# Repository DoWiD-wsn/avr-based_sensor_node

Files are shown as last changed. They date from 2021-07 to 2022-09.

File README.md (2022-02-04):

# AVR-based Sensor Node with Xbee (ASN(x))

The **A**VR-based **S**ensor **N**ode with **X**bee, short **ASN(x)**, is a low-cost platform for low-power sensor nodes specifically for (environmental) monitoring applications, both indoor and outdoor.
It was designed with a focus on energy efficiency and robustness.

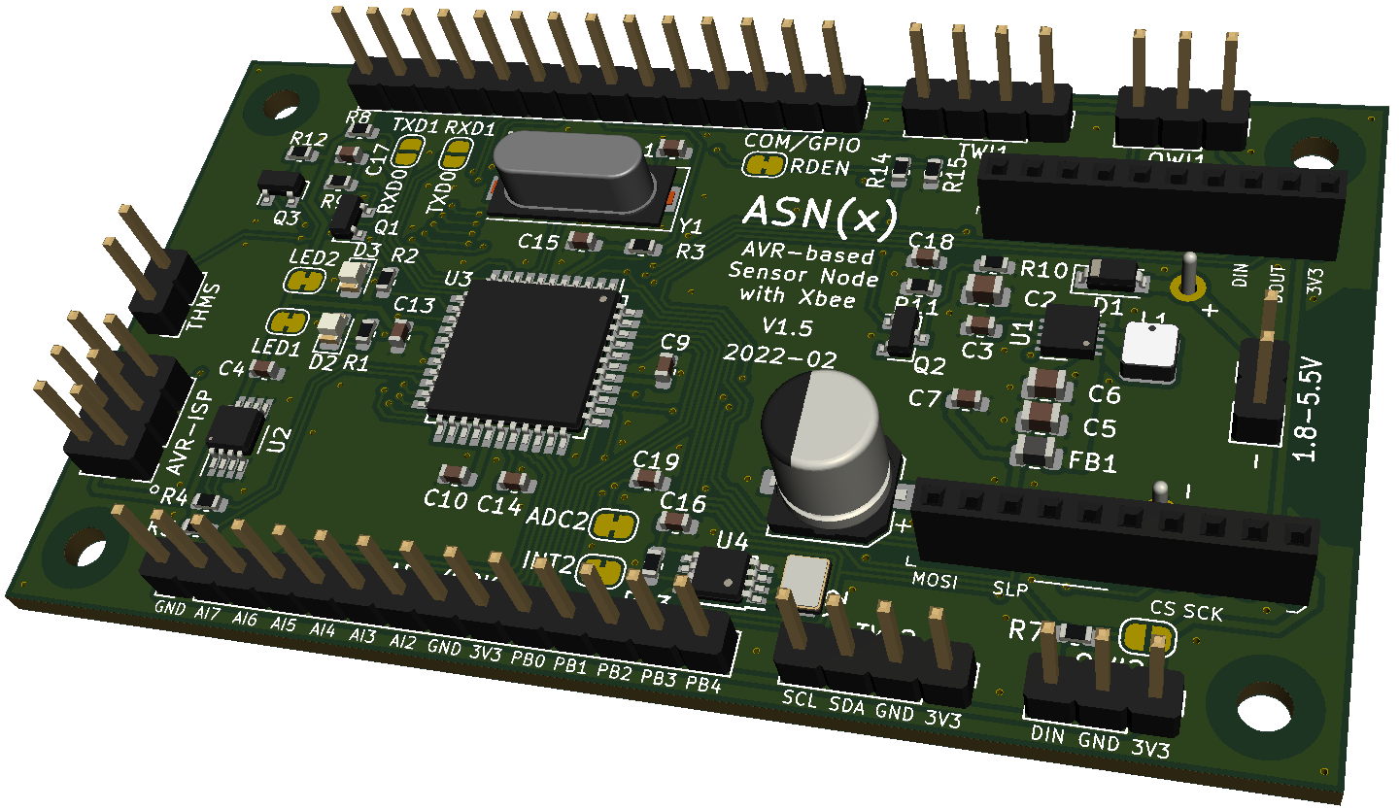
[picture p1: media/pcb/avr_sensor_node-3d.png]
PCB 3D (/media/pcb/avr_sensor_node-3d.png)


## Key Facts

* Compact size of 77 x 43.5 mm
* Powered by two AA batteries (but not limited to; see below)
* [ATmega1284P](docs/datasheets/ATmega1284P.pdf) low-power 8-bit MCU (running at 4MHz)
    * 128kB flash memory
    * 16kB SRAM
    * 4kB EEPROM
* Two UART interfaces
    * one for the radio transceiver
    * one for debug purposes or loopback self-tests
* Programmable via [6-pin AVR-ISP](https://www.mikrocontroller.net/wikifiles/9/97/Avr-isp-pinout.png) connector
* On-board [TMP275](docs/datasheets/TMP275.pdf) temperature sensor (I²C)
* On-board [PCF85263ATT](docs/datasheets/PCF85263A.pdf) RTC as MCU wake-up source (I²C; INT2)
* Fixed 3.3V DC/DC converter [TPS63031DSKR](docs/datasheets/TPS63031DSKR.pdf)
    * Input voltage range: 1.8V to 5.5V
    * Energy efficiency (node power-down): >= 65%
    * Energy efficiency (node active): >= 80%
    * Optimized for low-power mode (<100mA)
* Xbee radio socket
    * UART and SPI connected
    * sleep-request and sleep-indicator pins connected
* Two low-current user LEDs (can be disconnected via cut-through solder jumpers)
* Two solder jumpers to enable bridging of UART0 and UART1 (for loopback self-tests)
* Onboard resistor divider for ADC self-test 
* Onboard resistor divider for battery voltage measurement
* Onboard connector for thermistor temperature measurements
* Two one-wire interface (OWI) connectors (incl. pull-up resistors; separate data pins)
* Two two-wire interface (TWI/I²C) connectors (incl. pull-up resistors)
* 2x14-pin expansion headers

## Contents

```
.
├── docs                : documents & project documentation
│   └── datasheets      : datasheets of components used
├── kicad               : KiCad files
├── media               : Miscellaneous media (images, etc.)
│   ├── pcb             : Photos and rendered images of the PCB
│   └── schematic       : SVG images of the schematics
└── source              : C code library and example programs
```

For more information on the PCB (and its design) refer to [docs/pcb_design.md](docs/pcb_design.md).
The C code library, its functionality, and usage as well as example scripts are presented in [docs/code_library.md](docs/code_library.md).

## Built with

* [KiCad EAD 5.1.9](https://kicad.org/) - PCB design
* [avr-gcc 5.4.0](https://gcc.gnu.org/wiki/avr-gcc) - C code library
* [avr-libc 2.0.0](https://www.nongnu.org/avr-libc/) - C code library

## Contributors

* **Dominik Widhalm** - [***DC-RES***](https://informatics.tuwien.ac.at/doctoral/resilient-embedded-systems/) - [*UAS Technikum Wien*](https://embsys.technikum-wien.at/staff/widhalm/)

Contributions of any kind to improve the project are highly welcome.
For coding bugs or minor improvements simply use pull requests.
However, for major changes or general discussions please contact [Dominik Widhalm](mailto:widhalm@technikum-wien.at?subject=ASN(x)%20on%20GitHub).

## Publications

- Dominik Widhalm, Karl M. Goeschka, and Wolfgang Kastner, "*An open-source wireless sensor node platform with active node-level reliability for monitoring applications*", Sensors 21, no. 22: 7613, 2021, DOI: [10.3390/s21227613](https://doi.org/10.3390/s21227613)

## Changelog

A list of prior versions and changes between the updates can be found in the [CHANGELOG.md](CHANGELOG.md) file.
Note that the major and minor number refer to the hardware version of the ASN(x) board while the patch version is used to denote subsequent software versions.

## Known Issues

A list of known issues with the ASN(x) is available in the [ISSUES.md](ISSUES.md) file.
In this file, we keep track of all kinds of problems/bug and possible fixes for them.

## License

This project is licensed under the MIT License - see the [LICENSE.md](LICENSE.md) file for details.

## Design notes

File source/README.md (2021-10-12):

# ASN(x) C Code Library #

The *ASN(x) C Code Library* is a collection of (mainly) self-written ANSI-C libraries and test applications for the *ASN(x)* sensor node.
It offers basic functionality and helper functions for a range of tasks needed to develop a wireless sensor node based on the *ASN(x)*.
The build system is makefile-based and requires only a minimum number of other libraries and tools.

## Prerequisites ##

In the following, the software requirements for Debian/Ubuntu and Windows machines are listed.

### Debian/Ubuntu ###

To use the *ASN(x) C Code Library*, you need to have `avr-gcc`, `AVR Libc`, and `AVRDUDE` installed:  
  `sudo apt install gcc-avr avr-libc avrdude`  
That's basically it :)

Additionally, to generate the doxygen-based documentation, `doxygen` and `graphviz` are required where the latter one is needed to generate the call-graphs:  
  `sudo apt install doxygen graphviz`

### Windows ###

For Windows-based machines, the `WinAVR` tool can be used. Just download it from [Sourceforge](https://sourceforge.net/projects/winavr/) and install it; it includes `gcc-avr`, `avr-libc`, and `avrdude`. After installing it, you can use the tools from the [windows command prompt](https://www.makeuseof.com/tag/a-beginners-guide-to-the-windows-command-line/).

`Doxygen` can be acquired from [here](https://www.doxygen.nl/download.html) and `Graphviz` can be downloaded from [here](https://graphviz.org/download/).

## Directory Structure ##

```
.
├── _asnx_lib_                         : ASN(x) library files
├── makefile.in                        : Superior makefile to be included
├── 000-blinky_demo                    : Blinky demo to check the toolchain
├── 001-adc_uart_demo                  : ADC to UART output demo
├── 002-sensor_demo                    : Sensor reading demo
├── 003-xbee_demo                      : XBee basic communication demo
├── 004-sensor_node_demo               : Full sensor node demo
├── xyz                                : Further applications
└── ...
```

## AVRDUDE Basic Usage ##

Flashing the MCU and setting its fuses is done with [AVRDUDE](https://www.nongnu.org/avrdude/).
The basic commands are:
* **Flashing**:  
  `avrdude -p atmega1284p -c avrispv2 -P /dev/ttyACM0 -v -U flash:w:BINARY.hex`  
  The same can be achieved via the makefile by executing:  
  `make flash`
* **Erasing**:  
  `avrdude -p atmega1284p -c avrispv2 -P /dev/ttyACM0 -v -e`  
  The same can be achieved via the makefile by executing:  
  `make erase`
* **Write fuses**:
    * *Low fuses*:  
      `avrdude -p atmega1284p -c avrispv2 -P /dev/ttyACM0 -v -U lfuse:w:0xXX:m`
    * *High fuses*:  
      `avrdude -p atmega1284p -c avrispv2 -P /dev/ttyACM0 -v -U hfuse:w:0xXX:m`
    * *Extended fuses*:  
      `avrdude -p atmega1284p -c avrispv2 -P /dev/ttyACM0 -v -U efuse:w:0xXX:m`
    * The default fuse setings for the ASN(x) are:  
      `avrdude -p atmega1284p -c avrispv2 -P /dev/ttyACM0 -v -U lfuse:w:0xED:m -U hfuse:w:0xD9:m -U efuse:w:0xFF:m`  
      The same can be achieved via the makefile by executing:  
      `make defaultfuses`

## XBee 3 Zigbee ##

The XBee 3 is a powerful radio offering a wide range of functions.
In addition to Zigbee, 802.15.4 and Digimesh support (selectable by writing the appropriate firmware), it also has a BLE interface (disabled by default).
Using the BLE interface, you can configure the module using a smartphone in combination with the _Digi XBee Mobile_ app.
However, if you use the XBee for the first time and/or want to configure fresh modules, it is advisable to use Digi's [XCTU](https://www.digi.com/products/embedded-systems/digi-xbee/digi-xbee-tools/xctu) tool on a PC (Windows, Linux, Mac).
For that purpose, you will need to use a XBee to serial adapter such as the [Wavexhare XBee USB Adapter](https://www.waveshare.com/wiki/XBee_USB_Adapter).
Alternatively, the configuration can also be done via the UART interface and AT commands.

There is a [list of libraries](https://www.digi.com/resources/documentation/Digidocs/90001456-13/concepts/c_xbee_libraries_api_mode.htm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) available to interface with the XBee modules.
In addition, you can simply use the module in transparent mode (tunnel UART) or program your own API function (e.g., as shown for [ATmega32](https://www.electronicwings.com/avr-atmega/xbee-interfacing-with-atmega32)).

### Configuration for ASN(x) ###

In the following, the basic configuration of the XBee 3 modules for the use with our ASN(x) sensor nodes is described.
Depending on your application, requirements, etc. you may need to adapt certain parameters.
The explanation of the particular parameters and example configurations can be found in the [XBee 3 User Manual](https://www.digi.com/resources/documentation/digidocs/pdfs/90001539.pdf).
If you use the [XCTU](https://www.digi.com/products/embedded-systems/digi-xbee/digi-xbee-tools/xctu) tool for the configuration, the parameters are grouped to categories; the same as we use below.
Parameters not mentioned in the list below are left at their initial/default value.

* **Networking**
    * `CE` (_device role_)  
        set to `0` (join network).
    * `ID` (_extended PAN ID_)  
        set to a defined address, e.g., `FEDCBA9876543210`.

* **Discovery Options**
    * `NI` (_node identifier_)  
        you can set a user-defined name; we use `SNx` for our devices where `x` is a consecutive number.

* **RF Interfacing**
    * `PL` (_TX power level_)  
        to save energy, we use the lowest value `0` (-5 dBm).

* **Sleep Settings**
    * `SM` (_sleep mode_)  
        to enable the sleep mode, set this value to `1` (pin hibernate).  
        Be careful to have the sleep-request pin at the right logic level; otherwise the XBee goes to sleep and will not be accessible anymore!

* **Bluetooth Options**
    * We use the BLE interface during development to have an easy access to the XBee's setting via the [Digi XBee mobile app](https://www.digi.com/products/embedded-systems/digi-xbee/digi-xbee-tools/digi-xbee-mobile-app).  
        However, in the actual deployment, the BLE interface is deactivated to save energy and for security reasons.
    * `BT` (_Bluetooth enable_)  
        activate the BLE interface by setting this parameter to `1` (you will be asked to set a BLE password).
    * `BI` (_Bluetooth identifier_)  
        optionally, a user-defined BLE identifier can be set to easily identify the single XBees in the mobile app.  
        We use `XBee SNx` where the `SNx` part matches the _NI_ described above.  
        The prefix `XBee` is used to filter the available Bluetooth devices in the mobile app (i.e., only show Bluetooth devices whose identifier starts with `XBee`).
    * `BP` (_Bluetooth power_)  
        to save energy, we use the lowest value `0` (-20 dBm).

* **API Configuration**
    * `AP` (_API enable_)  
        we use the XBee in API mode, therefore, set this parameter to `1` (API mode without escapes).

* **UART Interface**
    * We use the default setting of the UART interface (i.e., 9600 8N1).
    * `BD` (_UART baud rate_)  
        set to `3` (9600 b/s)
    * `NB` (_UART parity_)  
        set to `0` (no parity)
    * `SB` (_UART stop bits_)  
        set to `0` (one stop bit)

* **I/O Settings**
    * To save energy, we deactivate the GPIOs usually used for status information.  
        However, be careful to leave the sleep request and asleep indicator assigned, especially when using pin hibernation!
    * `D5` (_DIO5/Associate Configuration_)  
        set to `0` (disabled)
    * `D8` (_DIO8/Sleep_Rq_)  
        set to `1` (DTR/Sleep_Rq)
    * `D9` (_DIO9/Sleep Indicator_)  
        set to `1` (Awake/Asleep indicator)
    * `P0` (_DIO10/RSSI Configuration_)  
        set to `0` (disabled)

### Resources ###

If you face troubles with the XBee module, have a look at the [common XBee mistakes](https://www.faludi.com/projects/common-xbee-mistakes/) summary.

#### XBee firmwares ####

* [Zigbee](https://www.digi.com/products/embedded-systems/digi-xbee/rf-modules/2-4-ghz-rf-modules/xbee3-zigbee-3)
* [802.15.4](https://www.digi.com/products/embedded-systems/digi-xbee/rf-modules/2-4-ghz-rf-modules/xbee3-802-15-4)
* [Digimesh](https://www.digi.com/products/embedded-systems/digi-xbee/rf-modules/2-4-ghz-rf-modules/xbee3-digimesh-2-4)

#### XBee libraries ####

* [XBee mbed Library](https://os.mbed.com/teams/Digi-International-Inc/code/XBeeLib/)
* [Digi XBee Ansi C Library](https://github.com/digidotcom/xbee_ansic_library/)
* [XBee-arduino](https://github.com/andrewrapp/xbee-arduino)

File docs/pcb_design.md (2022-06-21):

# ASN(x) - PCB Design

The board was designed with KiCad `version 5.1.9` and mainly uses schematic symbols and PCB footprints available in the [KiCad libraries](https://kicad.org/libraries/download/).
Parts not included in these libraries are available as project-specific libraries (see below).
The design requires only a two-layer PCB with all components placed on the top side.
Also, it has enough ground zone area to avoid heating or EMI issues.

## Contents

```
kicad/
├── 3dshapes                        : 3D models of PCB parts
├── myfootprint.pretty              : custom PCB footprints
├── bom                             : interactive HTML BOM
├── avr_sensor_node.kicad_pcb       : PCB layout file
├── avr_sensor_node.pro             : KiCad project file
├── avr_sensor_node.sch             : schematic layout file
├── fp-lib-table                    : project-specific footprint library list
├── mycomponents.dcm                : custom schematic library (descriptions, aliases and keywords)
├── mycomponents.lib                : custom schematic library
└── sym-lib-table                   : project-specific symbol library list
```

## Costs

The cost of one *ASN(x)* is around 20€ for the components (2021-05; [Farnell](https://www.farnell.com/)), around 10€ for the PCB ([PCB Pool / Beta Layout](https://eu.beta-layout.com/pcb/)), and around 20€ for the Xbee 3 radio (normal version, not pro).
Thus, the total costs of one *ASN(x)* are around **50€**.
Depending on the supplier and quantities ordered, the costs may vary.

## Schematic

**Main schematic**:  
Main Schematic (/media/schematic/avr_sensor_node.svg)

## Header Pinout
 
PCB header pinout (/media/pcb/avr_sensor_node-pinout.svg)

## PCB Design

Front:  
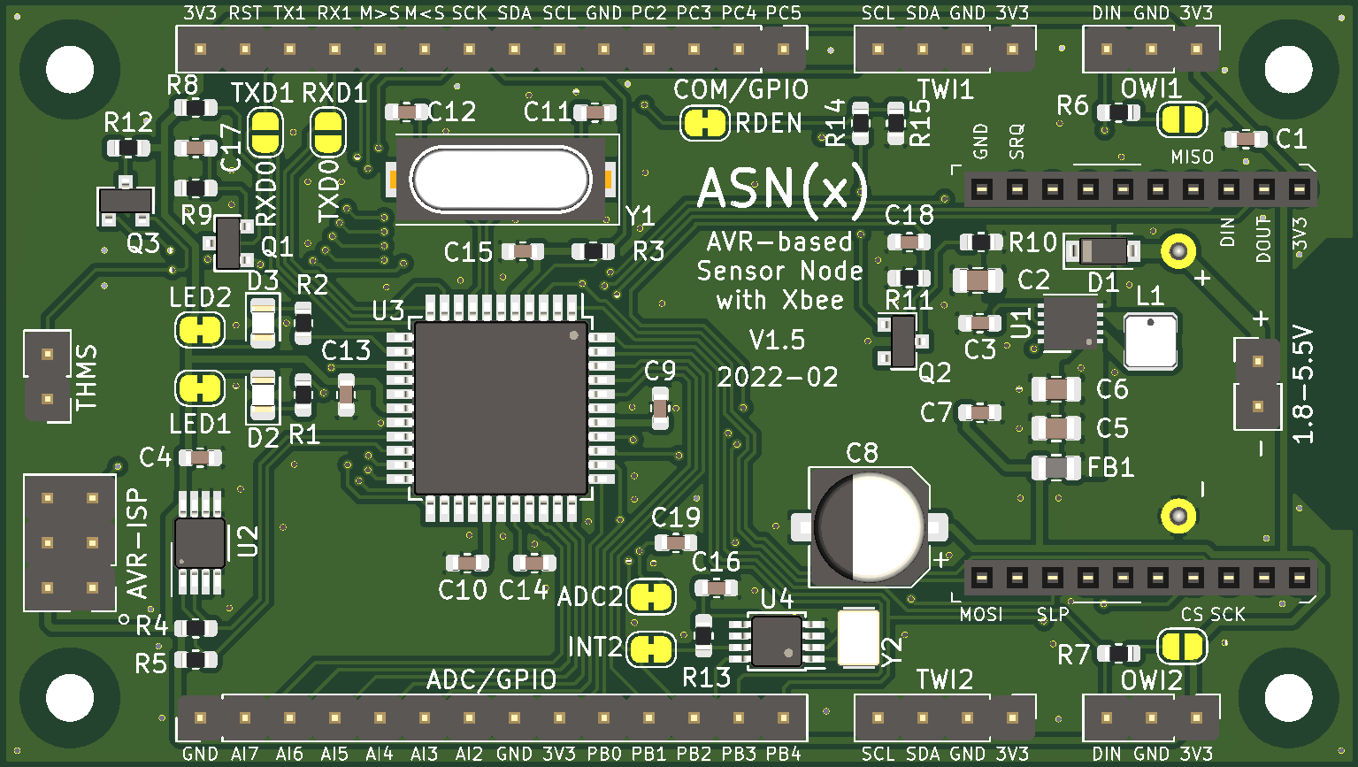
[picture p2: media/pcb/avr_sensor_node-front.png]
PCB front (/media/pcb/avr_sensor_node-front.png)


Back:  
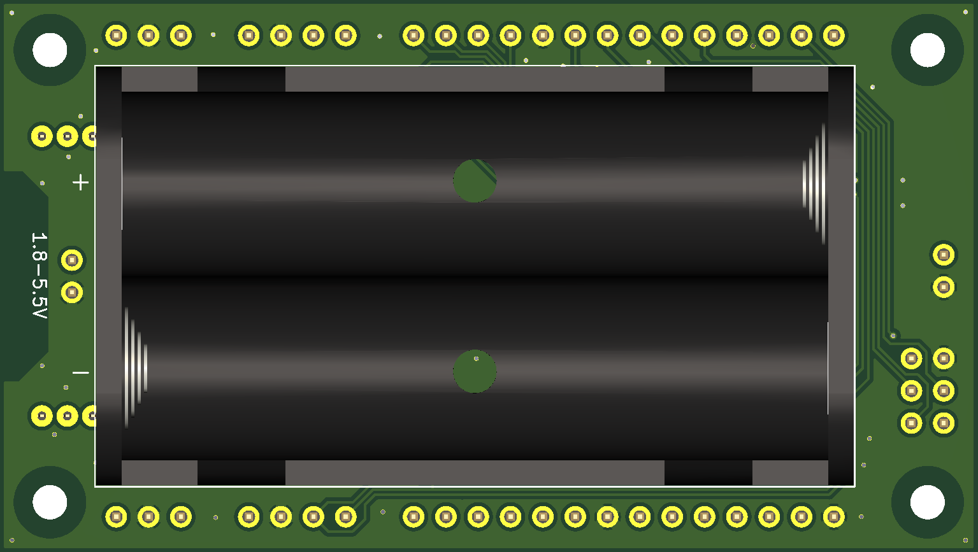
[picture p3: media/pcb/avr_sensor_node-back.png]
PCB back (/media/pcb/avr_sensor_node-back.png)


For the PCB design the following rules were used:
* Design rules:
    * Minimum track width: `0.15 mm`
    * Minimum via diameter: `0.6 mm`
    * Minimum via drill: `0.3 mm`
    * Minimum hole to hole: `0.25 mm`
    * `Prohibit overlapping courtyards`
* Tracks:
    * `0.2 mm`
    * `0.25 mm`
    * `0.4 mm`
    * `0.8 mm`
* Vias:
    * Size: `0.6 mm`
    * Drill: `0.3 mm`
* Zones:
    * Clearance: `0.3 mm`
    * Minimum width: `0.18 mm`
    * Pad connections: `Thermal reliefs`
    * Thermal clearance: `0.18 mm`
    * Thermal spoke width: `0.8 mm`

## Components and Libraries

An interactive BOM can be found in the `/kicad/bom/` directory (see [here](../kicad/bom/avr_sensor_node.html); created with [InteractiveHtmlBom](https://github.com/openscopeproject/InteractiveHtmlBom)).

| Reference | Value | Symbol Library | Symbol | Footprint Library | Footprint | Dist. |
|---|---|---|---|---|---|---|
| C11-C12 | 18pF  | Device | C | Capacitor_SMD | C_0603_1608Metric | [Farnell](https://at.farnell.com/kemet/c0603c180k5ractu/kondensator-18pf-50v-10-x7r-0603/dp/2821151) |
| C14 | 47nF  | Device | C | Capacitor_SMD | C_0603_1608Metric | [Farnell](https://at.farnell.com/yageo/cc0805krx7r9bb473/kondensator-0-047-f-50v-10-x7r/dp/718683) |
| C1,C3-C4,C7,C8,C10,C13,C15-C19  | 100nF | Device | C | Capacitor_SMD | C_0603_1608Metric | [Farnell](https://at.farnell.com/kemet/c0603c104m5ractu/kondensator-0-1-f-50v-20-x7r-0603/dp/2581046) |
| C2,C5,C6  | 10uF  | Device | C | Capacitor_SMD | C_0805_2012Metric | [Farnell](https://at.farnell.com/murata/grm21br71a106ka73l/kondensator-10-f-10v-10-x7r-0805/dp/2611944) |
| C8 | 100uF | Device | C | Capacitor_SMD | CP_Elec_6.3x7.7 | [Farnell](https://at.farnell.com/kemet/edk107m016a9gaa/kondensator-100-f-16v-radial-smd/dp/2068653) |
| L1 | 1.5uH | Device | L | *myfootprint*`*`  | L_Coilcraft_LPS3015 | [Farnell](https://at.farnell.com/coilcraft/lps3015-152mrb/induktivit-t-1-5uh-20-1-3a-gesch/dp/2408018?st=1.5) |
| FB1 | - | Device | Ferrite_Bead | Inductor_SMD | L_0805_2012Metric | [Farnell](https://at.farnell.com/laird/mi0805k400r-10/ferritperle-2012-100mhz-40r/dp/2292459) |
| R1-R2 | 560ohm | Device | R | Resistor_SMD | R_0603_1608Metric | [Farnell](https://at.farnell.com/yageo/ac0603fr-07560rl/dickschichtwiderstand-560r-1-0/dp/3495281) |
| R3-R15 | 10k | Device | R | Resistor_SMD | R_0603_1608Metric | [Farnell](https://at.farnell.com/yageo/ac0603fr-0710kl/dickschichtwiderstand-10k-1-0/dp/3495224) |
| D2-D3 | green | Device | LED | LED_SMD | LED_0805_2012Metric | [Farnell](https://at.farnell.com/kingbright/kp-2012lsgc/led-gr-n-0-8mcd-568nm-smd/dp/2463991) |
| D1 | schottky | Device  | D_Schottky | Diode_SMD | D_SOD-123 | [Farnell](https://at.farnell.com/stmicroelectronics/stps0520z/schottky-diode-2a-20v-smd/dp/1467545) |
| Q1-Q3 | BSS138 | Transistor_FET | BSS138 | Package_TO_SOT_SMD | SOT-23 | [Farnell](https://at.farnell.com/nexperia/bss138bk-215/mosfet-n-kanal-60v-0-36a-sot23/dp/2053833) |
| U2 | - | *mycomponents*`*` | TMP275 | Package_SO | VSSOP-8_3.0x3.0mm_P0.65mm | [Farnell](https://at.farnell.com/texas-instruments/tmp275aidgkr/temperature-sensor-0-0625deg-c/dp/3009081) |
| U3 | - | *mycomponents*`*` | ATmega1284P | Package_QFP | TQFP-44_10x10mm_P0.8mm | [Farnell](https://at.farnell.com/microchip/atmega1284p-au/mcu-8bit-avr-128k-flash-44tqfp/dp/1715480) |
| U1 | - | *mycomponents*`*` | TPS63031 | Package_SON | VSON-10-1EP_3x3mm_P0.5mm_EP1.2x2mm_ThermalVias | [Farnell](https://at.farnell.com/texas-instruments/tps63031dskr/dc-dc-conv-buck-boost-2-4mhz-vson/dp/3122997) |
| U4 | - | *mycomponents*`*` | PCF85263ATT | Package_SO | TSSOP-8_3x3mm_P0.65mm | [Farnell](https://at.farnell.com/nxp/pcf85263att-aj/echtzeituhr-5-5v-i2c-tssop-8/dp/2775936) |
| Y1 | 4MHz  | Device | Crystal | Crystal | Crystal_SMD_HC49-SD | [Farnell](https://at.farnell.com/txc/9c-4-000maaj-t/xtal-4-000mhz-18pf-smd-hc-49s/dp/1842332) |
| Y2 | 32.768kHz  | Device | Crystal | Crystal | Crystal_SMD_3215-2Pin_3.2x1.5mm | [Farnell](https://at.farnell.com/abracon/abs07-lr-32-768khz-6-1-t/quarz-32-768khz-6pf-3-2mm-x-1/dp/2849465) |
| J6,J9 | - | Connector_Generic | Conn_01x02 | Connector_PinHeader_2.54mm | PinHeader_1x02_P2.54mm_Vertical | [Farnell](https://at.farnell.com/wurth-elektronik/61304011121/stiftleiste-2-54mm-tht-vertikal/dp/2356175) |
| J2-J3 | - | Connector_Generic | Conn_01x03 | Connector_PinHeader_2.54mm | PinHeader_1x03_P2.54mm_Vertical | [Farnell](https://at.farnell.com/wurth-elektronik/61304011121/stiftleiste-2-54mm-tht-vertikal/dp/2356175) |
| J4-J5 | - | Connector_Generic | Conn_01x04 | Connector_PinHeader_2.54mm | PinHeader_1x04_P2.54mm_Vertical | [Farnell](https://at.farnell.com/wurth-elektronik/61304011121/stiftleiste-2-54mm-tht-vertikal/dp/2356175) |
| J7-J8 | - | Connector_Generic | Conn_01x14 | Connector_PinHeader_2.54mm | PinHeader_1x14_P2.54mm_Vertical | [Farnell](https://at.farnell.com/wurth-elektronik/61304011121/stiftleiste-2-54mm-tht-vertikal/dp/2356175) |
| J1 | - | Connector | AVR-ISP-6 | Connector_PinHeader_2.54mm | PinHeader_2x03_P2.54mm_Vertical | [Farnell](https://at.farnell.com/wurth-elektronik/61304021121/stiftleiste-2-54mm-tht-vertikal/dp/2356148) |
| JP1 | Xbee | *mycomponents*`*` | Xbee3 | *myfootprint*`*` | XBEE-20_THT | [Farnell](https://at.farnell.com/te-connectivity/1-2314878-0/buchsenleiste-10pos-1-reihe-2mm/dp/3289695) |
| JP2-JP3,JP6-JP7 | bridged | Jumper | SolderJumper_2_Bridged | Jumper | SolderJumper-2_P1.3mm_Bridged_RoundedPad1.0x1.5mm | - |
| JP4-JP5,JP9-JP10| open | Jumper | SolderJumper_2_Open | Jumper | SolderJumper-2_P1.3mm_Open_RoundedPad1.0x1.5mm | - |
| H1-H4 | - | Mechanical | MountingHole  | MountingHole | MountingHole_2.7mm_M2.5 | - |

If your installation of KiCad is missing (some of) the standard libraries, you can download them from [KiCad libraries](https://kicad.org/libraries/download/).
The custom libraries required (marked with `*`) are all contained in this repository.

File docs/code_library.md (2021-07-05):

# ASN(x) C Code Library #

The ASN(x) comes with a software library written in ANSI-C language, called `ASNX LIB`, to lower the entry barrier and ease the development of the node's software.
It provides a set of modules for the interaction with the AVR MCU's on-chip peripherals (e.g., ADC, UART, timer), several external sensor libraries connected via I²C or a one-wire interface (OWI), a high-level library to communicate with the Xbee 3 radio transceiver, and high level modules to support unit conversions as well as packing sensor values into messages (including a fixed-point number representation).

The libraries where self-written (unless otherwise specified) and have only a small number of dependencies.
That is, they only require `AVR Libc` to be available on the system and a recent version of `avr-gcc` for the compilation.
To flash the application on the MCU, either the tools provided by [Atmel](https://www.microchip.com/en-us/development-tools-tools-and-software) or `AVRDUDE` can be used.
For more information on the installation of those and the basic usage of `AVRDUDE` refer to the source directory's [README](../source/README.md).

To further ease the development of the ASN(x) software part, we provide a superior makefile that offers basic functionality in a convenient way, namely
* `flash` ... the flashing of a binary onto the MCU
* `clean` ... the cleaning of intermediate files
* `erase` ... the erasing of the MCU (clear the flash memory)
* `defaultfuses` ... the programming of the default fuse settings (lb: `0xDD`, hb: `0xD9`, eb: `0xff`)
* `doc` ... the generation of the libraries doxygen documentation
* `distclean` ... the cleaning of everything, that is, intermediate files and documentary

The generation of the documentation requires doxygen and dotviz (to generate the call-graphs), see [README](../source/README.md).

## ASNX LIB dependencies ##

As mentioned above, the ASN(x) software library has only little external dependencies (i.e., `AVR Libc`).
Additionally, the internal structure was kept shallow to minimize the modules' cross-dependencies and keep the software complexity as low as reasonably possible.

## Prepared demo applications ##

In the source directory, you can also find five pre-prepared demo applications.
They show the usage of the `ASNX LIB` and the ASN(x) components in a bottom-up fashion.

### 000-blinky_demo ###

The `blinky demo` is intended to help getting familiar with the toolchain and getting the hardware up and running (i.e., compilation and flashing of the software)
If everything worked, the two user LEDs will blink alternately with a delay of 500ms.
This demo only uses the `LED` module.

### 001-adc_uart_demo ###

The second demo application additionally shows the usage of the `ADC` and the `UART` modules as well as a simple `printf` library.
In the demo, the MCU's supply voltage and the battery voltage are read once per second (via the `ADC`) and the results are printed using the `printf` library on the `UART1` interface.

### 002-sensor_demo ###

The `sensor demo` depicts the usage of the provided external sensor libraries and the timer-based systick timer.
The following sensors are currently supported:
* DS18B20 temperature sensor (OWI)
* AM2302 temperature/humidity sensor (DHT22; OWI)
* BME280 environmental sensor (TWI)
* TMP275 on-board temperature sensor (TWI)
* LM75 temperature sensor (similar to TMP275; TWI)
* STEMMA soil humidity sensor (TWI)

Additionally, the MCU surface temperature measurement via the on-board voltage divider and an external 103JT thermistor (10kOhm @25°C) based on the Steinhart–Hart equation is supported.
All sensor values are read and printed via UART in a definable interval controlled by the systick timer.

### 003-xbee_demo ###

The fourth demo application shows the interaction with the Xbee 3 radio module connected via UART0.
It sends a steadily increasing number via unicast to a specified network participant (specified via its 64-bit MAC address) every 2 seconds and checks the transmission response (acknowledgment).

### 004-sensor_node_demo ###

The last demo, the full `sensor node demo`, shows an example of a full sensor node including Xbee communication, sensor readings, and sleep modes.
In this demo also the on-board RTC is used as a wake-up source for the MCU when it is sleeping.
Basically, the sensor node is woken up every 10 minutes (interval can be configured), reads the current sensor values, sends them to a defined network participant and goes back to sleep (power-down mode).
In addition to the basic sensor readings, also some diagnostic data are sent.

## Development of an own application ##

To create an own application, we suggest the following procedure:
* Create a new directory in the source folder.
* Create a C source file in the newly created directory (e.g., `APPLICATION_NAME.c`)
* Put a makefile into the new directory that contains at least:
  * `TARGET = APPLICATION_NAME`
  * `include ../makefile.in`
  * Additionally, also the port or other specific settings can be configured in the makefile.

That's it.
You are ready to code your own application.

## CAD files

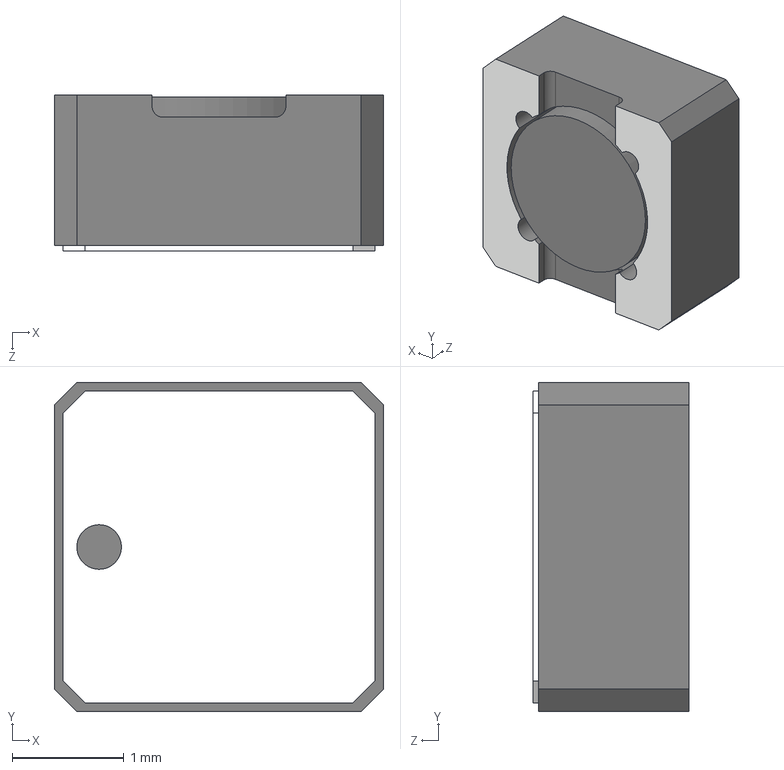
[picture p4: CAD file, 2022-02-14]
kicad/3dshapes/L_Coilcraft_LPS3015.step
2.95 x 2.95 x 1.40 mm

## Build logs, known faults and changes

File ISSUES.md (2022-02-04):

# Known Issues

In the following, known issues with the ASN(x) soft- or hardware are listed and possible fixes are provided.
Currently, the following issues are known:

* [DC/DC Converter Startup](#dcdc-converter-startup)

## DC/DC Converter Startup

The ASN(x) uses a [TPS63031DSKR](docs/datasheets/TPS63031DSKR.pdf) low-power DC/DC converter with a fixed output voltage of 3.3 V.
While providing a stable supply for the sensor node with a comparably high energy efficiency, we found one issue that may be bothersome during sensor node software development.
That is, when a voltage supply is connected to the DC/DC converter's output (e.g., by an AVR ISP programmer with built-in supply) the converter sometimes does not start-up (work) properly, even if the second source is removed.

A solution to this issue is to make sure not to drive the programmers (or whatever is connected) internal supply; most AVR ISP programmer we found allow one to disable the supply voltage.
However, in case you face this issue it normally helps to remove all power sources from the ASN(x) and leave it unpowered for several minutes.
Normally, after that the sensor node can be normally used again.

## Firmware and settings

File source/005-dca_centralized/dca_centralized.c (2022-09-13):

/*!
 * @brief   Implementation of a centralized DCA for fault detection
 *
 * Implementation of the dendritic cell algorithm (DCA) in a centralized
 * manner to detect faults. The DCA itself runs on the sink node, but
 * the detection is augmented by the node-level fault indicators that
 * are reported by every sensor node in the network.
 *
 * The procedure is as follows:
 * 1.)  initialize modules
 * 2.)  connect to the Zigbee network
 * 3.1) reset RTC (stop-watch mode)  <--+
 * 3.2) enable modules/sensors          |
 * 3.3) query sensors                   |
 * 3.4) perform self-diagnostics        |
 * 3.5) send values via Zigbee          |
 * 3.6) disable modules/sensors         |
 * 3.7) put MCU to sleep                |
 *  +-----------------------------------+
 *
 * @file    /005-dca_centralized/dca_centralized.c
 * @author  Dominik Widhalm
 * @version 2.2.0
 * @date    2022/09/13
 */


/*** APP CONFIGURATION ***/
#define ENABLE_DBG                  0               /**< Enable debug output via UART1 (9600 BAUD) */
#define ENABLE_DBG_MSG              0               /**< Enable debug output of message content */
#define ENABLE_DBG_INDICATOR        0               /**< Enable debug output of indicator values */
#define UPDATE_INTERVAL             5               /**< Update interval [min] */
#define ASNX_VERSION_MINOR          5               /**< Minor version number of the used ASN(x) */
/* Zigbee network */
#define ZIGBEE_ENABLE_ACK           0               /**< Enable (1) or disable (0) transmit response */
/* Enable (1) or disable (0) sensor measurements */
#define ENABLE_DS18B20              0               /**< enable DS18B20 sensor */
#define ENABLE_AM2302               0               /**< enable AM2302 sensor */
#define ENABLE_SHTC3                0               /**< enable SHTC3 sensor */
#define ENABLE_SHT30                1               /**< enable SHT30 sensor (addon board) */
/* Check configuration */
#if (ENABLE_AM2302 && ENABLE_SHTC3) || (ENABLE_AM2302 && ENABLE_SHT30) || (ENABLE_SHTC3 && ENABLE_SHT30)
#  error "Use either AM2302, SHTC3 or SHT30 for air measurements, but not several!"
#endif


/***** INCLUDES *******************************************************/
/*** STD ***/
#include <math.h>
/*** AVR ***/
#include <avr/io.h>
#include <avr/interrupt.h>
#include <avr/sleep.h>
#include <avr/wdt.h>
#include <util/delay.h>
/*** ASNX LIB ***/
/* MCU */
#include "adc/adc.h"
#include "hw/led.h"
#include "i2c/i2c.h"
#include "timer/timer.h"
#include "uart/uart.h"
/* Radio */
#include "xbee/xbee.h"
#if ASNX_VERSION_MINOR>0
/* RTC */
#  include "rtc/pcf85263.h"
#else
/* SysTick */
#  include "timer/systick.h"
#endif
/* Sensors */
#include "sensors/tmp275.h"
#if ENABLE_DS18B20
#  include "sensors/ds18x20.h"
#endif
#if ENABLE_AM2302
#  include "sensors/dht.h"
#endif
#if ENABLE_SHTC3
#  include "sensors/shtc3.h"
#endif
#if ENABLE_SHT30
#  include "sensors/sht30.h"
#endif
/* Misc */
#include "util/diagnostics.h"
#include "util/fixed_point.h"
#include "util/sensor_msg.h"
#if ENABLE_DBG
#  include "util/printf.h"
#else
#  define printf(...) do { } while (0)
#endif
/* DCA */
#include "dca/indicators.h"


/***** STRUCTURES *****************************************************/
/*!
 * A structure to store the sensor and indicator values.
 */
typedef struct {
    /* additional data */
    uint16_t time;          /**< timestamp (2 byte) */
    /* use case data */
    uint16_t t_air;         /**< air temperature (fixed point) */
    uint16_t h_air;         /**< air humidity (fixed point) */
    uint16_t t_soil;        /**< soil temperature (fixed point) */
    uint16_t h_soil;        /**< soil humidity (fixed point) */
    /* battery SoC */
    uint8_t soc;            /**< battery state-of-charge (fixed point) */
    /* indicator */
    uint8_t danger;         /**< danger indicator (fixed point) */
    uint8_t safe;           /**< safe indicator (fixed point) */
} MSG_t;


/***** GLOBAL VARIABLES ***********************************************/
#if ASNX_VERSION_MINOR==0
/*! Variable (flag) for barrier synchronization */
volatile uint8_t barrier = 1;
#endif
/*!
 * Put a MCUSR register dump into the .noinit section.
 * @see https://www.nongnu.org/avr-libc/user-manual/group__avr__watchdog.html
 */
uint8_t MCUSR_dump __attribute__ ((section (".noinit"))) \
                   __attribute__ ((used));             // Needed for LTO


/***** LOCAL FUNCTION PROTOTYPES **************************************/
void get_mcusr(void) __attribute__((naked)) \
                     __attribute__((section(".init3"))) \
                     __attribute__((used));            // Needed for LTO
void sleep_until_reset(void);
#if ASNX_VERSION_MINOR==0
void update(void);
#endif
#if ENABLE_DBG_MSG
void dbg_print_msg(MSG_t* msg);
#endif
#if ENABLE_DBG_INDICATOR
void dbg_print_indicator(float danger, float safe, float x_nt, float x_vs, float x_bat, float x_art, float x_rst, float x_ic, float x_adc, float x_usart, float t_air_i, float h_air_i, float t_soil_i, float h_soil_i);
#endif


/***** LOCAL FUNCTIONS ************************************************/
/*!
 * Turn off the WDT as early in the startup process as possible.
 * @see https://www.nongnu.org/avr-libc/user-manual/group__avr__watchdog.html
 */
void get_mcusr(void) {
    /* Make a copy of the MCUSR */
    MCUSR_dump = MCUSR;
    /* Reset the actual MCUSR */
    MCUSR = 0;
    /* Disable the WDT */
    wdt_disable();
}


/*!
 * Activate WDT with given delay, put MCU to sleep and wait for reset.
 */
void sleep_until_reset(void) {
    /* Enable Watchdog with 60ms delay */
    wdt_enable(WDTO_60MS);
    /* Put MCU to sleep */
    sleep_enable();
    sleep_bod_disable();
    sleep_cpu();
}


#if ASNX_VERSION_MINOR==0
/***
 * Callback function to be called by the systick timer.
 ***/
void update(void) {
    static uint8_t cnt = 0;
    /* Check if update time has elapsed */
    if(++cnt >= UPDATE_INTERVAL) {
        /* Reset counter */
        cnt = 0;
        /* Set barrier sync flag */
        barrier = 1;
    }
}
#endif


/*!
 * Debug: print the contents of a given sensor message structure
 */
#if ENABLE_DBG_MSG
void dbg_print_msg(MSG_t* msg) {
    printf("\n===== SENSOR MESSAGE CONTENTS =====\n");
    printf("%d message updates\n",msg->time);
    printf("=== SENSOR VALUES ===\n");
    printf("T_air: %.2f C\n",fp_fixed16_to_float_10to6(msg->t_air));
    printf("H_air: %.2f %%\n",fp_fixed16_to_float_10to6(msg->h_air));
    printf("T_soil: %.2f C\n",fp_fixed16_to_float_10to6(msg->t_soil));
    printf("H_soil: %.2f %%\n",fp_fixed16_to_float_10to6(msg->h_soil));
    printf("=== BATTERY ===\n");
    printf("SoC: %d\n",msg->soc);
    printf("=== SENSOR VALUES ===\n");
    printf("Danger: %.2f\n",fp_fixed8_to_float_2to6(msg->danger));
    printf("Safe: %.2f\n",fp_fixed8_to_float_2to6(msg->safe));
    printf("===================================\n\n");
}
#endif


/*!
 * Debug: print the values of the single indicator shares
 */
#if ENABLE_DBG_INDICATOR
void dbg_print_indicator(float danger, float safe, float x_nt, float x_vs, float x_bat, float x_art, float x_rst, float x_ic, float x_adc, float x_usart, float t_air_i, float h_air_i, float t_soil_i, float h_soil_i) {
    printf("\n===== INDICATOR VALUES =====\n");
    printf("danger: %.2f\n",danger);
    printf("safe: %.2f\n",safe);
    printf("=== DANGER/FAULT INDICATORS ===\n");
    printf("X_NT: %.2f\n",x_nt);
    printf("X_VS: %.2f\n",x_vs);
    printf("X_BAT: %.2f\n",x_bat);
    printf("X_ART: %.2f\n",x_art);
    printf("X_RST: %.2f\n",x_rst);
    printf("X_IC: %.2f\n",x_ic);
    printf("X_ADC: %.2f\n",x_adc);
    printf("X_UART: %.2f\n",x_usart);
    printf("=== SAFE INDICATORS ===\n");
    printf("T_AIR: %.2f\n",t_air_i);
    printf("H_AIR: %.2f\n",h_air_i);
    printf("T_SOIL: %.2f\n",t_soil_i);
    printf("H_SOIL: %.2f\n",h_soil_i);
    printf("===================================\n\n");
}
#endif


/***** MAIN ***********************************************************/
/*!
 * Main function of the application.
 */
int main(void) {
    /*** Local variables ***/
    /* Message data structure */
    MSG_t msg = {0};
#if ASNX_VERSION_MINOR>0
    /* Date/time structure */
    PCF85263_CNTTIME_t time = {0};
#endif
    /* Sensor handles */
    TMP275_t tmp275;                /* TMP275 sensor device structure */
#if ENABLE_DS18B20
    DS18X20_t ds18b20;              /* DS18B20 sensor device structure */
    uint8_t ds18b20_en = 0;         /* Sensor enable flag */
#endif
#if ENABLE_AM2302
    DHT_t am2302;                   /* AM2302 sensor device structure */
    uint8_t am2302_en = 0;          /* Sensor enable flag */
#endif
#if ENABLE_SHTC3
    SHTC3_t shtc3;                  /* SHTC3 sensor device structure */
    uint8_t shtc3_en = 0;           /* Sensor enable flag */
#endif
#if ENABLE_SHT30
    SHT30_t sht30;                  /* SHT30 sensor device structure */
    uint8_t sht30_en = 0;           /* Sensor enable flag */
#endif
    /* Temporary sensor measurement variables */
#if (ENABLE_DS18B20 || ENABLE_AM2302 || ENABLE_SHTC3 || ENABLE_SHT30)
    float measurement = 0.0;
#endif
#if (ENABLE_AM2302 || ENABLE_SHTC3 || ENABLE_SHT30)
    float measurement2 = 0.0;
#endif
    /* Diagnostic values */
    float v_bat=0.0, v_mcu=0.0, v_trx=0.0;
    float t_mcu=0.0, t_trx=0.0, t_brd=0.0;
    /* Sensor values */
    float t_air_t=0.0, h_air_t=0.0, t_soil_t=0.0, h_soil_t=0.0;
    /* Fault indicator */
    float x_nt=0.0, x_vs=0.0, x_bat=0.0, x_art=0.0, x_rst=0.0, x_ic=0.0, x_adc=0.0, x_usart=0.0;
    /* Safe indicator */
    float t_air_i=0.0, h_air_i=0.0, t_soil_i=0.0, h_soil_i=0.0;
    safe_t t_air_s, h_air_s, t_soil_s, h_soil_s;
    /* Aggregated indicator */
    float danger=0.0, safe=0.0;
    /* Runtime measurement */
    uint16_t runtime = 0, runtime_ms = 0;
    /* Function return value */
    int8_t ret = 0;


    /*** 1.) initialize modules ***************************************/
    /* Configure the sleep mode */
    set_sleep_mode(SLEEP_MODE_PWR_DOWN);
    /* Disable unused hardware modules */
#if ASNX_VERSION_MINOR>0
    PRR0 = _BV(PRTIM2) | _BV(PRTIM0) | _BV(PRSPI);
#else
    PRR0 = _BV(PRTIM2) | _BV(PRSPI);
#endif
    
#if ENABLE_DBG
    /* Initialize UART1 for debug purposes (9600 baud) */
    uart1_init(9600UL);
    /* Initialize the printf function to use the uart1_write_char() function for output */
    printf_init(uart1_write_char);
#else
    /* Disable UART1 */
    PRR0 |= _BV(PRUSART1);
#endif
    /* Print welcome message */
    printf("=== STARTING UP ... ===\n");
    
    /* Initialize the user LEDs and disable both by default */
    led_init();
    /* Initialize the ADC */
    adc_init(ADC_ADPS_32,ADC_REFS_VCC);
    adc_disable_din(0x07);
    /* Initialize I2C master interface */
    i2c_init();
    /* Initialize Xbee 3 (uses UART0 @9600 baud; receive via ISR) */
    uart0_init(9600UL);
    uart0_interrupt_enable();
    xbee_init(uart0_write_byte, uart0_pop_byte, uart0_rx_buffer_cnt);
    /* Status message */
    printf("Communication interfaces initialized ...\n");
    
    /* Initialize the diagnostic circuitry */
    diag_init();
    diag_disable();
    /* Initialize the fault indicators */
    indicators_init();
    /* Initialize the safe indicators */
    safe_init(&t_air_s);
    safe_init(&h_air_s);
    safe_init(&t_soil_s);
    safe_init(&h_soil_s);
    /* Status message */
    printf("Indicators initialized ...\n");

#if ASNX_VERSION_MINOR>0
    /* Initialize the RTC */
    time.minutes = UPDATE_INTERVAL;
    ret = pcf85263_init_wakeup_src(&time);
    if(ret != PCF85263_RET_OK) {
        printf("Couldn't initialize RTC (%d) ... aborting!\n",ret);
        sleep_until_reset();
    }
    /* Configure INT2 to fire interrupt when logic level is "low" */
    EICRA = 0x00;
    EIMSK = _BV(INT2);
#else
    /* Initialize the systick timer */
    systick_init();
    /* Set a systick callback function to be called every second */
    systick_set_callback_min(update);
#endif

    /* Enable interrupts globally */
    sei();

    /* Initialize the TMP275 sensor */
    ret = tmp275_init(&tmp275, TMP275_I2C_ADDRESS);
    if(ret != TMP275_RET_OK) {
        printf("Couldn't initialize TMP275 (%d) ... aborting!\n",ret);
        sleep_until_reset();
    }
    /* Configure the TMP275 sensor (SD; 10-bit mode) */
    ret = tmp275_set_config(&tmp275, 0x21);
    if(ret != TMP275_RET_OK) {
        printf("Couldn't configure TMP275 (%d) ... aborting!\n",ret);
        sleep_until_reset();
    }
    /* Status message */
    printf("TMP275 initialized ...\n");

#if ENABLE_DS18B20
    /* Initialize the DS18B20 sensor */
    ret = ds18x20_init(&ds18b20, &DDRD, &PORTD, &PIND, PD6);
    if(ret != DS18X20_RET_OK) {
        printf("Couldn't initialize DS18B20 (%d)!\n",ret);
        ds18b20_en = 0;
    } else {
        printf("DS18B20 initialized ...\n");
        ds18b20_en = 1;
    }
#endif

#if ENABLE_AM2302
    /* Initialize the AMS2302 sensor */
    ret = dht_init(&am2302, &DDRD, &PORTD, &PIND, PD7, DHT_DEV_AM2302);
    if(ret != DHT_RET_OK) {
        printf("Couldn't initialize AMS2302 (%d)!\n",ret);
        am2302_en = 0;
    } else {
        printf("AMS2302 initialized ...\n");
        am2302_en = 1;
    }
#endif

#if ENABLE_SHTC3
    /* Initialize the SHTC3 sensor */
    ret = shtc3_init(&shtc3, SHTC3_I2C_ADDRESS);
    if(ret != SHTC3_RET_OK) {
        printf("Couldn't initialize SHTC3! (%d)\n",ret);
        shtc3_en = 0;
    } else {
        printf("SHTC3 initialized ...\n");
        shtc3_en = 1;
    }
#endif

#if ENABLE_SHT30
    /* Initialize the SHT30 sensor */
    ret = sht30_init(&sht30, SHT30_I2C_ADDRESS);
    if(ret != SHT30_RET_OK) {
        printf("Couldn't initialize SHT30! (%d)\n",ret);
        sht30_en = 0;
    } else {
        printf("SHT30 initialized ...\n");
        sht30_en = 1;
    }
#endif

    
    /*** 2.) connect to the Zigbee network ****************************/
    /* Check Xbee module connection */
    printf("Connecting to Zigbee network ... ");
    ret = xbee_wait_for_connected();
    if(ret != XBEE_RET_OK) {
        printf("\nERROR connecting to the network (%d) ... aborting!\n",ret);
        /* Wait for watchdog reset */
        sleep_until_reset();
    }
    /* Print status message */
    printf("connected!\n");


    while(1) {
#if ASNX_VERSION_MINOR>0
        /*** (Re-)enable I2C interface ***/
        /* Reset the TWI */
        i2c_reset();
        
        /*** 3.1) reset RTC (stop-watch mode) *************************/
        /* Stop RTC */
        ret = pcf85263_stop();
        if(ret != PCF85263_RET_OK) {
            printf("Couldn't stop RTC (%d) ... aborting!\n",ret);
            sleep_until_reset();
        }
        /* Reset time structure for stop-watch reset below */
        pcf85263_clear_stw_time(&time);
        /* Reset stop-watch time */
        pcf85263_set_stw_time(&time);
        /* Start RTC */
        ret = pcf85263_start();
        if(ret != PCF85263_RET_OK) {
            printf("Couldn't re-start RTC (%d) ... aborting!\n",ret);
            sleep_until_reset();
        }
#else
        /*** 3.1) barrier synchronization *****************************/
        /* Wait until the barrier sync flag is set */
        while(barrier == 0);
        /* Reset barrier sync flag */
        barrier = 0;
#endif

        /*** 3.2) enable modules/sensors ******************************/
        /* Wake-up xbee */
        ret = xbee_sleep_disable();
        if(ret != XBEE_RET_OK) {
            printf("Couldn't wake-up xbee radio (%d) ... aborting!\n",ret);
            /* Wait for watchdog reset */
            sleep_until_reset();
        }
        
        /* Start timer1 with prescaler 1024 -> measurement interval [256us; 16.78s] */
        timer1_start(TIMER_PRESCALER_1024);
        
        /* Enable ADC */
        adc_enable();
        /* Enable the self-diagnostics */
        diag_enable();

        /*** 3.3) query sensors ***************************************/
#if ENABLE_DS18B20
        /* Check if sensor is ready */
        if(ds18b20_en == 0) {
            /* Try to initialize sensor (again) */
            if(ds18x20_init(&ds18b20, &DDRD, &PORTD, &PIND, PD6) == DS18X20_RET_OK) {
                printf("Successfully (re-)initialized DS18B20!\n");
                ds18b20_en = 1;
            }
        }
        if(ds18b20_en == 1) {
            /* DS18B20 - Temperature in degree Celsius (°C) */
            ret = ds18x20_get_temperature(&ds18b20, &measurement);
            if(ret == DS18X20_RET_OK) {
                printf("... DS18B20 temperature: %.2f\n", measurement);
                t_soil_t = measurement;
                msg.t_soil = fp_float_to_fixed16_10to6(t_soil_t);
                x_ic_dec(X_IC_DEC_NORM);
            } else {
                printf("... DS18B20 reading failed (%d)\n",ret);
                t_soil_t = 0.0;
                msg.t_soil = 0;
                x_ic_inc(X_IC_INC_NORM);
            }
        } else {
            t_soil_t = 0.0;
            msg.t_soil = 0;
        }
#endif

#if ENABLE_AM2302
        /* Check if sensor is ready */
        if(am2302_en == 0) {
            /* Try to initialize sensor (again) */
            if(dht_init(&am2302, &DDRD, &PORTD, &PIND, PD7, DHT_DEV_AM2302) == DHT_RET_OK) {
                printf("Successfully (re-)initialized AM2302!\n");
                am2302_en = 1;
            }
        }
        if(am2302_en == 1) {
            /* AM2302 - Temperature in degree Celsius (°C) and relative humidity in percent (% RH) */
            ret = dht_get_temperature_humidity(&am2302, &measurement, &measurement2);
            if(ret == DHT_RET_OK) {
                printf("... AM2302 temperature: %.2f\n", measurement);
                printf("... AM2302 humidity: %.2f\n", measurement2);
                t_air_t = measurement;
                h_air_t = measurement2;
                msg.t_air = fp_float_to_fixed16_10to6(t_air_t);
                msg.h_air = fp_float_to_fixed16_10to6(h_air_t);
                x_ic_dec(X_IC_DEC_NORM);
            } else {
                printf("... AM2302 reading failed (%d)\n",ret);
                t_air_t = 0.0;
                h_air_t = 0.0;
                msg.t_air = 0;
                msg.h_air = 0;
                x_ic_inc(X_IC_INC_NORM);
            }
        } else {
            t_air_t = 0.0;
            h_air_t = 0.0;
            msg.t_air = 0;
            msg.h_air = 0;
        }
#endif

#if ENABLE_SHTC3
        /* Check if sensor is ready */
        if(shtc3_en == 0) {
            /* Try to initialize sensor (again) */
            if(shtc3_init(&shtc3, SHTC3_I2C_ADDRESS) == SHTC3_RET_OK) {
                printf("Successfully (re-)initialized SHTC3!\n");
                shtc3_en = 1;
            }
        }
        if(shtc3_en == 1) {
            /* SHTC3 - Temperature in degree Celsius (°C) and relative humidity in percent (% RH) */
            ret = shtc3_get_temperature_humidity(&shtc3, &measurement, &measurement2, 1);
            if(ret == SHTC3_RET_OK) {
                printf("... SHTC3 temperature: %.2f\n", measurement);
                printf("... SHTC3 humidity: %.2f\n", measurement2);
                t_air_t = measurement;
                h_air_t = measurement2;
                msg.t_air = fp_float_to_fixed16_10to6(t_air_t);
                msg.h_air = fp_float_to_fixed16_10to6(h_air_t);
                x_ic_dec(X_IC_DEC_NORM);
            } else {
                printf("... SHTC3 reading failed (%d)\n",ret);
                t_air_t = 0.0;
                h_air_t = 0.0;
                msg.t_air = 0;
                msg.h_air = 0;
                x_ic_inc(X_IC_INC_NORM);
            }
        } else {
            t_air_t = 0.0;
            h_air_t = 0.0;
            msg.t_air = 0;
            msg.h_air = 0;
        }
#endif

#if ENABLE_SHT30
        /* Check if sensor is ready */
        if(sht30_en == 0) {
            /* Try to initialize sensor (again) */
            if(sht30_init(&sht30, SHT30_I2C_ADDRESS) == SHT30_RET_OK) {
                printf("Successfully (re-)initialized SHT30!\n");
                sht30_en = 1;
            }
        }
        if(sht30_en == 1) {
            /* SHT30 - Temperature in degree Celsius (°C) and relative humidity in percent (% RH) */
            ret = sht30_get_temperature_humidity(&sht30, &measurement, &measurement2);
            if(ret == SHT30_RET_OK) {
                printf("... SHT30 temperature: %.2f\n", measurement);
                printf("... SHT30 humidity: %.2f\n", measurement2);
                t_air_t = measurement;
                h_air_t = measurement2;
                msg.t_air = fp_float_to_fixed16_10to6(t_air_t);
                msg.h_air = fp_float_to_fixed16_10to6(h_air_t);
                x_ic_dec(X_IC_DEC_NORM);
            } else {
                printf("... SHT30 reading failed (%d)\n",ret);
                t_air_t = 0.0;
                h_air_t = 0.0;
                msg.t_air = 0;
                msg.h_air = 0;
                x_ic_inc(X_IC_INC_NORM);
            }
        } else {
            t_air_t = 0.0;
            h_air_t = 0.0;
            msg.t_air = 0;
            msg.h_air = 0;
        }
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

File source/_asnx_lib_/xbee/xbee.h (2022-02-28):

/*!
 * @brief   ASN(x) Xbee 3 library -- header file
 *
 * Library to the Xbee 3 module accessible via UART.
 *
 * @file    /_asnx_lib_/xbee/xbee.h
 * @author  Dominik Widhalm
 * @version 1.3.8
 * @date    2022/02/28
 */

#ifndef _ASNX_XBEE_H_
#define _ASNX_XBEE_H_

/***** INCLUDES *******************************************************/
/*** STD ***/
#include <stdint.h>
#include <stddef.h>
/*** AVR ***/
#include <util/delay.h>
/*** ASNX LIB ***/
#include "hw/hw.h"


/***** DEFINES ********************************************************/
/* Xbee sleep-request pin (default) */
#define XBEE_SLEEP_REQ_DDR                  (DDRC)
#define XBEE_SLEEP_REQ_PORT                 (PORTC)
#define XBEE_SLEEP_REQ_PIN                  (PINC)
#define XBEE_SLEEP_REQ_GPIO                 (PC6)
/* Xbee sleep-indicator pin (default) */
#define XBEE_SLEEP_IND_DDR                  (DDRC)
#define XBEE_SLEEP_IND_PORT                 (PORTC)
#define XBEE_SLEEP_IND_PIN                  (PINC)
#define XBEE_SLEEP_IND_GPIO                 (PC7)

/*! Join network attempt retries */
#define XBEE_JOIN_RETRIES                   (200)
/*! Join network delay between tries [ms] */
#define XBEE_JOIN_DELAY                     (50)

/*! Wake-up attempt retries */
#define XBEE_WAKE_RETRIES                   (200)
/*! Wake-up delay between tries [ms] */
#define XBEE_WAKE_DELAY                     (25)

/*! Response receive attempts */
#define XBEE_RESPONSE_ATTEMPTS              (5)
/*! Response attempt retries */
#define XBEE_RESPONSE_RETRIES               (25)
/*! Response delay between tries [ms] */
#define XBEE_RESPONSE_DELAY                 (25)

/*! Maximum Number of Transmission Bytes (for transparent mode) */
#define XBEE_CONF_NP                        (54)
/*!
 * Unicast transmission maximum payload size.
 * XBee Zigbee firmware supports fragmentation that allows a single
 * large data packet to be broken up into multiple RF transmissions and
 * reassembled by the receiver before sending data out its serial port.
 */
#define XBEE_CONF_PAYLOAD_MAX               (84)

/* Network source 64-bit addressing */
#define XBEE_ADDR64_USE16                   (0x000000000000FFFF)
#define XBEE_ADDR64_BROADCAST               (0xFFFFFFFFFFFFFFFF)
#define XBEE_ADDR64_COORDINATOR             (0x0000000000000000)
/* Network source 16-bit addressing */
#define XBEE_ADDR16_UKNOWN                  (0xFFFE)
#define XBEE_ADDR16_ALL_ROUTER              (0xFFFC)
#define XBEE_ADDR16_ALL_NON_SLEEP           (0xFFFD)
#define XBEE_ADDR16_ALL_DEVICES             (0xFFFF)
#define XBEE_ADDR16_COORDINATOR             (0x0000)
#define XBEE_ADDR16_USE64                   (XBEE_ADDR16_UKNOWN)
/* DH - Destination Address High */
#define XBEE_DH_BROADCAST                   (0x00000000)
#define XBEE_DH_COORDINATOR                 (0x00000000)
/* DL - Destination Address Low */
#define XBEE_DL_BROADCAST                   (0x0000FFFF)
#define XBEE_DL_COORDINATOR                 (0x00000000)

/* Xbee API mode delimiter */
#define XBEE_START_DELIMITER                (0x7E)

/* Remote command options */
#define XBEE_ATCMD_REMOTE_OPT_NO            (0x00)
#define XBEE_ATCMD_REMOTE_OPT_NACK          (0x01)
#define XBEE_ATCMD_REMOTE_OPT_APPLY         (0x02)
#define XBEE_ATCMD_REMOTE_OPT_SECURE        (0x10)
#define XBEE_ATCMD_REMOTE_OPT               (XBEE_ATCMD_REMOTE_OPT_APPLY)

/* Broadcast transmit radius */
#define XBEE_TRANSMIT_BROADCAST_RADIUS      (0x00)
/* Transmit command options */
#define XBEE_TRANSMIT_OPT_NO                (0x00)
#define XBEE_TRANSMIT_OPT_NACK              (0x01)
#define XBEE_TRANSMIT_OPT_INDIRECT_BINDING  (0x04)
#define XBEE_TRANSMIT_OPT_MULTICAST         (0x08)
#define XBEE_TRANSMIT_OPT_SECURE            (0x10)
#define XBEE_TRANSMIT_OPT_APS_ENCRYPTION    (0x20)
#define XBEE_TRANSMIT_OPT_EXT_TIMEOUT       (0x40)
#define XBEE_TRANSMIT_OPT                   (XBEE_TRANSMIT_OPT_NO)


/***** ENUMERATION ****************************************************/
/*! Enumeration for the Xbee function returns values */
typedef enum {
    XBEE_RET_OK                         = 0,    /**< SUCCESS */
    XBEE_RET_ERROR                      = -1,   /**< ERROR: general error */
    XBEE_RET_INVALID_CMD                = -2,   /**< ERROR: invalid command given */
    XBEE_RET_INVALID_PARAM              = -3,   /**< ERROR: invalid parameter given */
    XBEE_RET_FAILED_TRANSMISSION        = -4,   /**< ERROR: transmission failed */
    XBEE_RET_NOT_SECURE                 = -5,   /**< ERROR: no secure connection */
    XBEE_RET_ENCRYPTION_ERROR           = -6,   /**< ERROR: encryption error */
    XBEE_RET_CMD_NOT_SECURE             = -7,   /**< ERROR: command not secure */
    XBEE_RET_INVALID_CRC                = -8,   /**< ERROR: CRC check failed */
    XBEE_RET_INVALID_FRAME              = -9,   /**< ERROR: invalid frame given */
    XBEE_RET_PAYLOAD_SIZE_EXCEEDED      = -10,  /**< ERROR: maximum payload size exceeded */
    XBEE_RET_FID_NOT_MATCH              = -11,  /**< ERROR: returned FID does not match */
    XBEE_RET_MAC_NOT_MATCH              = -12,  /**< ERROR: returned MAC does not match */
    XBEE_RET_ADDR_NOT_MATCH             = -13,  /**< ERROR: returned address does not match */
    XBEE_RET_TIMEOUT                    = -14   /**< ERROR: timeout */
} XBEE_RET_t;
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

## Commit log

2021-03-23 Added kicad files of ASN v1.0 (incl. own symbols/footprints)
    [avr_sensor_node.kicad_pcb, avr_sensor_node.ods, avr_sensor_node.sch]
2021-03-23 Added rendered image of ASN v1.0 PCB (front/back)
2021-03-29 Started with README Added schematics Added initial PCB docu
2021-03-29 Reworked PCB images
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2021-03-30 Fixed include paths in current library
    [bme280.c, ds18x20.c, i2c.c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]
2021-04-13 First demo for ASN(x) V1.0 (blinky; with updated HW and LED library)
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2021-04-13 Added UART demo (uses UART1 -> pin header) Changed xbee to UART0 Removed legacy fuses library (and dependencies) Fixed wrong default fuses in makefile
    [i2c.c, uart.c, xbee.c]
2021-04-13 Improved code documentation for previous modules Extended printf library to specify putc function
2021-04-13 Reworked and improved ADC library
    [adc.c]
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2021-04-14 Revert PCB design docu to last working state
2021-04-14 Fixed Vcc measurement in ADC lib
    [adc.c]
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2021-04-14 Reworked previous ASNX LIB modules
    [adc.c, temperature.h, uart.c]
2021-04-14 Reworked timer modules (tcnt/systick)
    [timer.h]
2021-04-14 Reworked I2C module
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2021-04-14 Updated schematic, PCB, and BOM (fixed part values and Farnell links)
    [avr_sensor_node.kicad_pcb, avr_sensor_node.ods, avr_sensor_node.sch]
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2021-04-14 Reworked OWI library and OWI-based sensor libraries
    [dht.c, ds18x20.c, ds18x20.h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]
2021-04-14 Renamed tcnt back to timer to avoid confusion
    [timer.h]
2021-04-14 Reworked sensor libraries
2021-04-14 Added sensor demo (AM2302 not working yet)
    [dht.c, ds18x20.c, ds18x20.h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]
2021-04-15 Bug fix in DHT library (works sometimes now, but not always)
    [dht.c, sensor_demo.c]
2021-04-15 Added PCB header pinout figure in PCB docu
2021-04-15 Reworked LM75 temperature sensor library Added TMP275 temperature sensor library Careful: both sensors have the same I2C base address -> solder LM75 A0 to Vcc!
    [lm75.c, tmp275.c, tmp275.h]
2021-04-15 Cont'd to bugfix DHT library ... not working yet (will continue ... soon)
    [dht.c, sensor_demo.c]
2021-04-16 Fixed DHT sensor library with low-level read from Davide Gironi
    [dht.c, sensor_demo.c]
2021-04-16 Reworked DS18X20 library (enabled better error handling)
    [ds18x20.c, ds18x20.h, sensor_demo.c]
2021-04-16 Extended I2C library with is_available function Reworked LM75/TMP275 library for better error handling and to support multiple devices with different addresses
    [i2c.c, i2c.h, lm75.c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]
2021-04-16 Added device structures to all I2C libraries Added better error handling Updated BME280 library Improved 02-sensor_demo
    [bme280.c, jt103.c, sensor_demo.c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]
2021-04-17 Fixed bug for 103JT in 002-sensor_demo
    [jt103.c, sensor_demo.c]
2021-04-19 Reworked sensor message library (single message per interval)
2021-04-19 Reworked sensor message and xbee library
    [timer.h, xbee.c, xbee.h]
2021-04-19 Fixed bug in newly introduced wait_for_connection() function in xbee library (and updated function headers)
    [xbee.c, xbee.h]
2021-04-19 Started preparing full sensor node demo (app 004)
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2021-04-20 Finished initial sensor node demo
    Enabled watchdog
    Implemented incident counter and reboot source
    Implemented dynamic sensor enable/disable in case of errors
    Implemented start-up LED blinky sequence
2021-04-20 Added additional debug output for sensor node demo and increment time struct field
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2021-04-20 Fixed WDT bug Added define to enable/disable debug output via UART1
2021-04-26 Updated sensor node demo (added Xbee temperature and supply voltage measurements)
2021-04-27 Fixed DS18B20 respectively OWI library and enable multiple sensors
    [ds18x20.c, ds18x20.h, owi.c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]
2021-04-27 Fixed typo in 04-sensor_node_demo
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2021-04-28 Added battery voltage measurement to sensor node demo
2021-05-05 Added xbee sleep demo (005; based on sensor node demo 004)
2021-05-06 Update ASN(x) PCB Added Vbat voltage divider Added Xbee sleep pull-down resistors Changed thermistor balance resistor to normal (1%) instead of 0.1% Update silk layer Unified header pin pads to circu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
    [avr_sensor_node.kicad_pcb, avr_sensor_node.sch]
2021-05-06 Update DHT lib to enable/disable last update check via systick timer
2021-05-07 Added PCF85263A to ASN(x) design (RTC; timer) Updated changelog Updated interactive BOM
    [avr_sensor_node.kicad_pcb, avr_sensor_node.sch]
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2021-05-07 Removed ODS BOM; have interactive BOM and PCB docu now
    [avr_sensor_node.ods]
2021-05-08 Added optional connector (2-pin header) for Vbat input
    [avr_sensor_node.kicad_pcb, avr_sensor_node.sch]
2021-05-12 Removed I2C init from device init functions to demo applications
2021-05-12 Changed Vbat voltage divider resistors to 100k (lesser current) Added solder-jumper (bridged) for RTC INTA and TS lines (both with 10k pull-up resistor) Added labels to LED solder-jumpers Updated PCB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
    [avr_sensor_node.kicad_pcb, avr_sensor_node.sch]
2021-05-18 Cont'd working on AVR sleep Minor improvements to ADC, UART and I2C library to better support sleep
2021-05-18 Minor updated on ASN(x) PCB
    [avr_sensor_node.kicad_pcb]
2021-05-19 Fixed xbee sleep pull-up resistors (sleep = high)
    [avr_sensor_node.kicad_pcb, avr_sensor_node.sch]
2021-05-19 Merged sleep functionality into sensor node demo (not final yet)
2021-05-19 Fixed AVR/xbee sleep issue in sensor node demo (xbee uses UART ISR mode)
    [uart.c, xbee.c, xbee.h]
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2021-05-19 Updated ASN(x) PSB (removed TS pull-up; has internal one)
    [avr_sensor_node.kicad_pcb, avr_sensor_node.sch]
2021-05-19 Added RTC TS-based active runtime measurement to sensor node demo (004)
2021-05-25 Removed RTC TS line from PCB design (granularity too low)
    [avr_sensor_node.kicad_pcb, avr_sensor_node.sch]
2021-05-25 Updated ASN(x) timer library and added timer3 Changed runtime measurement from RTC to timer1 (16 bit)
2021-05-26 Fixed default fuses in superior makefile
2021-05-26 Fixed runtime DBG print in sensor node demo (004)
2021-05-27 Switched ADC1 and ADC2 and added solder-jumper for ADC2
    [avr_sensor_node.kicad_pcb, avr_sensor_node.sch]
2021-05-28 DHT lib: separate sensor reading from getter functions
2021-06-02 Fixed wrong data indices in sensor node demo (004)
2021-06-02 Reworked ASN(x) PCB (see CHANGELOG) and started preparing V1.2 for production
    [avr_sensor_node.kicad_pcb, avr_sensor_node.sch]
2021-06-02 Minor fix in PCB (broken zone; header label)
    [avr_sensor_node.kicad_pcb]
2021-06-02 Added labels to VBAT header on both sides
    [avr_sensor_node.kicad_pcb]
2021-06-02 Added 1M resistor farnell link (other one was not available anymore)
2021-06-04 Improved PCB design for low-power operation (see CHANGELOG)
    [avr_sensor_node.kicad_pcb, avr_sensor_node.sch]
2021-06-04 Updated PCB and BOM (replaced single 10nF C with 100nF)
    [avr_sensor_node.kicad_pcb, avr_sensor_node.sch]
2021-06-07 Reworked ASNX LIB to meet doxygen rules
    [adc.c, bme280.c, dht.c]
2021-06-07 Switched from static to dynamic sensor message size for transmission
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2021-07-05 Switched RTC from 10-pin to 8-pin TSSOP (easier to acquire on the market
    [avr_sensor_node.kicad_pcb, avr_sensor_node.sch]
2021-07-08 Connected Xbee SPI signals to MCU
    [avr_sensor_node.kicad_pcb, avr_sensor_node.sch]
2021-08-05 Readded reworked DHT lib that got somehow missing in last merge (-> 1.2)
    [dht.c]
2021-08-09 Extended UART/ADC demo to show all ADC channels
2021-08-09 Rework for v1.3 Removed legacy components (R12/R13) Added MOSFET to enable/disable R_divider diagnostics Changed R_divider resistor to 10k
    [avr_sensor_node.kicad_pcb, avr_sensor_node.sch]
2021-08-09 Fixed 04-sensor_node_demo
2021-08-09 Re-enabled xbee in sensor node demo (forget when doing some tests)
2021-08-09 Fixed bug in DHT library (for combined reading)
    [dht.c]
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2021-08-09 Fixed missing measurement counter (cnt) in 04-sensor_node_demo
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2021-08-10 Added time-based decay function for reset-source indicator
    [diagnostics.c, diagnostics.h]
2021-08-10 04-sensor_node_demo: fixed xbee thresholds for WDT reset; added reset-source decay
    [xbee.h]
2021-08-10 Fixed reset-source indicator with decay
    [diagnostics.c, diagnostics.h]
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2021-08-11 Fixed bug in 04-sensor_node_demo (ADC self-test debug output)
2021-08-11 Fixed stupid typo in 04-sensor_node_demo
2021-08-11 Fixed nasty bug in 04-sensor_node_demo (incorrect delay for XBee-TX-wait() loop)
2021-08-11 Fixed missing message cnt-time initialization in 04-sensor_node_demo
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2021-08-13 Fixed and improvements to XBee/UART/CBuff library
    [uart.c, xbee.c, xbee.h]
2021-08-13 Adjust decay rate for reset-source indicator (0.92 decay, 0.1 minimum, input source 8 => 9h until 0)
    [diagnostics.h]
2021-09-02 Corrected type of on-board RTC in README
2021-09-16 Fixed bug regarding message number (time) in sensor node demo
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2021-09-28 Adapted SHTC3 library to enable chosing low-power/normal mode in the function call
2021-09-29 Fixed typos in SHTC3 library
    [shtc3.c]
2021-10-14 Updated ASN(x) PCB design Removed reset switch (not needed in normal operation) Added solder jumper (open) to OWI pull-ups Moved position of THMS header Added 1.5mm clearance to mounting holes
    [avr_sensor_node.kicad_pcb, avr_sensor_node.sch]
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2021-10-18 Manually merged legacy sensor demo code fragments into latest version (i.e., support for V1.0 boards)
2021-11-03 Removed unintentionally left label of reset button
    [avr_sensor_node.kicad_pcb]
2021-11-08 Changed diagnostic voltage divider resistors to 100k (lesser power; still accurate)
    [avr_sensor_node.kicad_pcb, avr_sensor_node.sch]
2021-11-08 Changed SHTC3 library as some sensors do not react to the stop condition
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2021-11-29 Fixed strict-prototypes issues in ASNX_LIB
    [timer.h, uart.c]
2021-11-29 Fixed missing-prototypes issues in ASNX_LIB
    [pcf85263.h, timer.h]
2021-11-29 Fixed write-strings issues in ASNX_LIB
    [xbee.c]
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2021-12-14 Added silk labels for expansion headers
    [avr_sensor_node.kicad_pcb]
2021-12-14 Improved sensor node demo (DHT library, WDT resets, checks, etc.)
2022-01-10 Changed Varef C to 47nF
    [avr_sensor_node.kicad_pcb, avr_sensor_node.sch]
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2022-01-31 Major update of ASN(x) libraries Bugfixes and improvements developed in dca branch
    [adc.c, diagnostics.c, diagnostics.h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]
2022-01-31 Updated all demo applications Adapt for new ASN(x) libraries Added DCA demo application (005) Removed diagnostics from sensor node demo (004)
2022-01-31 Updated PCB design Added decoupling capacitor to ADC inputs (self-diagnostics)
    [avr_sensor_node.kicad_pcb, avr_sensor_node.sch]
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2022-02-01 Further fixed in xbee library take care or fid mismatch in case another response is received inbetween adapted timeout times and handling
    [dca_centralized.c, xbee.c, xbee.h]
2022-02-01 Added indicator debug option to 005 demo (ftDCA) Increased Xbee timeouts (needed in case of high network load)
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2022-02-03 Stability improvements of ASNX-LIB and DCA demo Added more compiler warnings and enabled Werror Adapted Xbee timeouts (still a sporadic issue) Enabled compiler link-time optimization (-flto)
    [dca_centralized.c, xbee.c, xbee.h]
2022-02-04 Fixed nasty xbee timeout bug
    [xbee.c]
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2022-02-04 Released ASN(x) v1.5
    [avr_sensor_node.kicad_pcb, avr_sensor_node.sch]
2022-02-09 Fixed backport to ASN(x) v1.0 for 005 demo
    [dca_centralized.c]
2022-02-10 Fixed unnecessary delay in xbee receive routine
    [xbee.c]
2022-02-10 Fixed bug in 005 demo backport for ASN(x) v1.0
    [dca_centralized.c, xbee.c, xbee.h]
2022-02-10 Enabled power-down mode for wdt reset in ASN(x) v1.0 backport
    [dca_centralized.c]
2022-02-11 Further stability improvements in DCA demo (005) Increased xbee timeouts (sometimes reconnect takes longer) Removed LTO from make rules (caused problems with WDT) Some beautifications to dbg prints D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
    [dca_centralized.c, xbee.h]
2022-02-11 Fixed ISR issues in OWI sensors
    [dht.c, owi.c]
2022-02-11 Fixed missing bus release/drive in OWI libraries in case of errors (timeouts, etc.)
    [dht.c, owi.c, owi.h]
2022-02-14 Further stability improvements in DCA demo (005) Reworked xbee function timeouts (and increased values) Fixed WDT issue when using LTO
    [dca_centralized.c, xbee.c, xbee.h]
2022-02-14 Added missing 3d models for 3d preview
    [L_Coilcraft_LPS3015.step, avr_sensor_node.kicad_pcb]
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2022-04-12 Fixed lower boundary in battery SoC function
    [diagnostics.c, diagnostics.h]
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2022-04-13 Added SHT30 air temperature and relative humidity sensor library Some parts (e.g., CRC check, raw value conversion) are taken from SHTC3 library
2022-04-13 Reworked and extended sensor demo (002) Added BH1750 illuminance sensor Added SHT30 air temperature and relative humidity sensor Prepared for ZMOD air quality sensor; not implemented yet
    [sensor_demo.c]
2022-04-14 Started with ZMOD4410 gas sensor library Printf currently added for debug purposes (see init function) Basic structure and functionality added Init currently fails -> need to debug (more) Final IAQ c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
    [sensor_demo.c, zmod4410.c]
2022-04-14 Cont'd with ZMOD4410 gas sensor library Init function works now (silly bug in timeout check) Raw sensor data retrieving (ADC values) also tested and working Final IAQ value calculation still missing 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
    [sensor_demo.c, zmod4410.c]
2022-05-02 DHT library fix Set data pin to output (high) in init function
    [dht.c]
2022-06-21 Changed diagnostic resistor values back to 10k
    [avr_sensor_node.kicad_pcb, avr_sensor_node.sch]
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2022-09-13 Fixed DCA demo version number
    [dca_centralized.c]
